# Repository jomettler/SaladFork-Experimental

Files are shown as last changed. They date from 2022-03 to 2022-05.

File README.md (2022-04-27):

# SaladFork-Experimental
Repository for Mods by me for the [SaladFork](https://github.com/PrintersForAnts/Salad_Fork) 3D Printer

This is a developement repository. Assume that all uploads are untested. There is absolutely no warranty on anything. 

Feel free to open issues or contact me directly in case you find any bugs.

ALSO: Some Mods contain Parts at least partly designed by [ANNEX-ENGINEERING](http://annex-engineering.com) I am not allowed to include these parts in my CAD, and their License applies to their designs. Due to this, these Parts are uploaded always in a sub-dir with their License File, which you should read carefully. I hate it, but I don´t have the time to do everything on my own and their designs are certainly better than a lot of stuff out there.

## Coming Soon
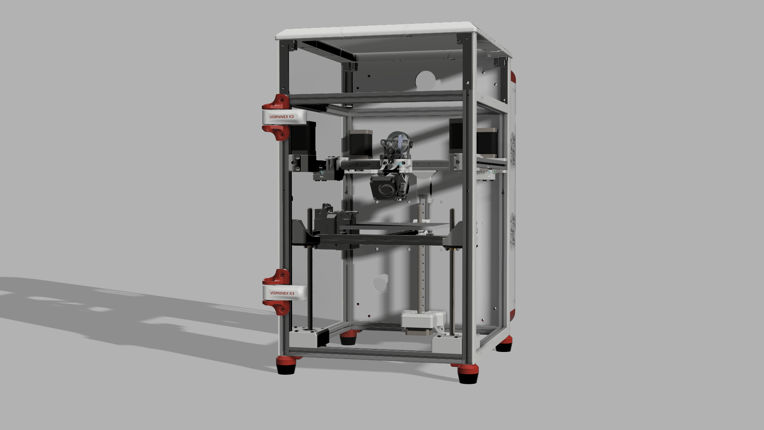
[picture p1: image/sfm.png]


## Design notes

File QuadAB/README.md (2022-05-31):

# Quad AB Drives for the SaladFork
Note that the XY Joints are basically mirrored compared to the orignal ones. They require the same build parts.The Idlers from the original tensioners are needed for the modificated drive mounts in the back.

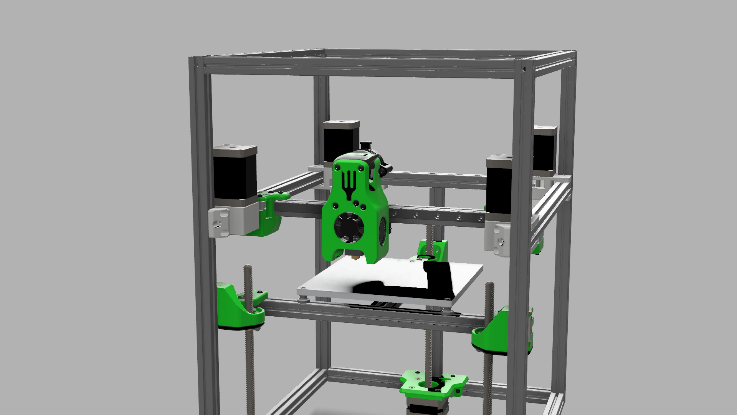
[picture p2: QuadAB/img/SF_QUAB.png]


## BOM
only additionaly needed parts are listed

2x NEMA14
2x Pulleys
screws & nuts

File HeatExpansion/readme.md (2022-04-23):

# heat expansion compensation stuff 

## General
This is most likely not relevant for small printers which print with a 0.4 Nozzle or bigger. The Machines below all have proven to work great for what they were (probably) designed for and they seem to meet critical criteria that is currently demanded both by manufactures and hobbyists. This area is of interest for higher precision machines and large builds that want to maintain the current stock precision. 

Heat sources: 
- hotend
- bed heater
- friction
- motors

A lot of work has been done on compensation for errors in printing resolution due to heat expansion (check out [tanaes](https://github.com/tanaes) nice work on the topic). Kinematic coupling for beds and titan or steel backers for gantry extrusions beeing the probably most popular solutions. But they usually come with some general flaws.

### [Annex K3](https://github.com/Annex-Engineering/Gasherbrum-K3):
While the Bed is directly mounted to extrusions, the kinematic coupling covers the expansion (and tilt) of the bed extrusions. The gantry rails are mounted in plastic or directly on the gantry extrusions. The design is inherently flawed concerning heat expansion of rails, frame (except bed extrusions) and bed.

### Voron [Trident](https://github.com/VoronDesign/Voron-Trident) / [Salad Fork](https://github.com/PrintersForAnts/Salad_Fork) / [2.4](https://github.com/VoronDesign/Voron-2) / [Micron](https://github.com/PrintersForAnts/Micron)
Titan and Steelbackers exist for the gantry extrusions. Kinematic mounting for the Bed. The bed extrusions (Trident style)/ gantry extrusions (2.4 Style) are mounted to the Z Rails using spherical bearings. Stock builds don´t have any solution for heat expansion errors. The designs are inherently flawed concerning expansion of the rails, frame, and bed. Also, the Z-Axis on these printers only work because of plastic beeing wobbly, due to massive overconstrain.

### Backers as a solution:
Backers follow a simple idea. If heat expansion creates a force in one direction that results in bending, we just need to create another force pulling in the opposite direction to compensate. But it neglects a lot of things: Thermal expansion is still happening and will induce stress into the system at various points. And they have a few obvious downsides since they are not 3D printable, take up space that could be utilized, expensive and add weight. It would be easier to not have this force in the first place, making compensating it unnecessary.

### Kinematic coupling for Beds:
Direct mounted Beds like on the [CroXY](https://github.com/CroXY3D/CroXY) are a simple and nice solution. But having extrusions to which the bed is mounted allows simple implementation of overtravel and cheaper beds. This benefit is kind of destroyed with the currently available kinematic couplings for beds, since they are usually CNC milled or cut from steel or titanium. This also adds unnecessary weight for moving Z machines and therefore make extrusion-mountable, 3D printed kinematic coupling for beds a necessity. 

### What about the Z-Rails?
Z Rails expand too. The solution with backers is just really inconvenient if panels are directly mounted from the opposite site. So usually no solution is applied.

## Mounting Linear Rails to Aluminium Extrusions:
The different heat expansion coefficient of the materials from the linear rails and extrusions results in a different elongation. Since they are static coupled, one of them can´t expand as much as necessary. This induces stress and, depending on the friction between the materials and material properties, leads to a bow. If we do not want this stress in our system, we need to allow the different elongation while preserving accuracy. The obvious solution for a 3D Printer is mounting the rail different.

Only one steel TNut is needed per rail. This one is mounted in the middle, the screw is fully tightend. This screw ideally locks all necessary degrees of freedom. Since it is not ideal, we support it a little. For all other holes in the rail, use a 3D printed TNut (preferably material with low friction coefficients). This nut should not apply ANY force in mounting direction of the rail, so just tighten them extremly gently with a little bit of loctide or something. Ideally, the printed nut fills the slot of the extrusion and is touching both, extrusion and rail. You can use a little bit of friction reducing material (grease, oil) between extrusion and nut. Also between Extrusion and Rail. Make sure the chosen material is compliant with the other components used. Now, heat expansion of the extrusion and the rail is decoupled. They can both elongate at their pace, since the printed TNuts can slide in the extrusion.

Note: The shape of your extrusions becomes a critical part for this kind of mount. Using quality extrusions is a necessity, else your rails might wobble in undesired directions.

Without the steel TNut tightend the rail should not wobble on the extrusion, but only move in the direction of the slot. You might have to tune your printer/slicer first.

## Bed
For the bed, we can use the exact same method. Instead of screwing it directly to the extrusions, we screw it on a plastic carriage that slides in the extrusion. This carriage needs low friction and high accuracy. On a V2.4 this still leaves the bed overconstrained. On a Trident style printer, this will result in a bed that is not expanding similar in all directions. Due to the T-like mounted bed extrusions, the fixed point of the bed moves to the front. This is probably irrelevant for small, 3-Axis machines, but might be an issue otherwise. Mounting the Bed extrusions Y-like solves this.

## Frame
With all rails decoupled from the frame, the frame can expand in all directions. Make sure that if your panels are directly bolted to the frame, the screws should not be tight and the mount holes in the panel should be a little oversized to allow elongation of the frame. Consider using only one steel TNut and TNuts printed in a material with low friction coefficients.

## This Repository
The STL Uploaded is for 15x15 extrusions according to the SF 150mm CAD. The f3d file can be used as an example how the Nut needs to be shaped to adapt for other extrusions. The STL should be printed with a 0.2 Nozzle, else issues might occur.

## Why no Data?
I enjoy using my brain and I don´t have enough time to test evertyhing by myself, so I though sharing might be a good thing in order to help others and myself. Data is highly appreciated. This repository does not intend to deliver a final answer or solution, but wants to introduce a possibly better approach for the problem at hand.

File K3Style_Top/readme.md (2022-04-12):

# K3 Style tophat for Saladfork

Inspired by the Tophat of the AnnexEngineering K3 (https://github.com/Annex-Engineering/Gasherbrum-K3)

Version for 10x3mm Magnets and 6x3mm Magnets

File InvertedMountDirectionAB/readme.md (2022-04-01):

# Adapted backside AB Drive Mounts for QuadAB

Mounts for AB Drives in the back. Adapted to mount the drive from the top. Endstop removed (sensorless homing)

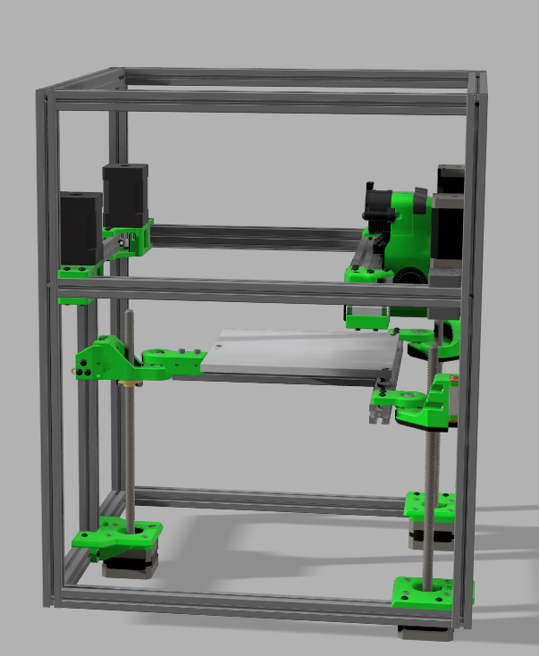
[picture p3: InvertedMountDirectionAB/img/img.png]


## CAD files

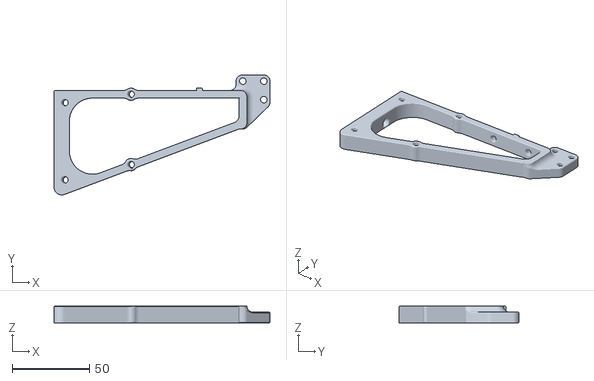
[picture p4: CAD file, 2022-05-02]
Misc/STL/SelfMaintenance/MountMain_x1.stl
140.0 x 77.8 x 11.0

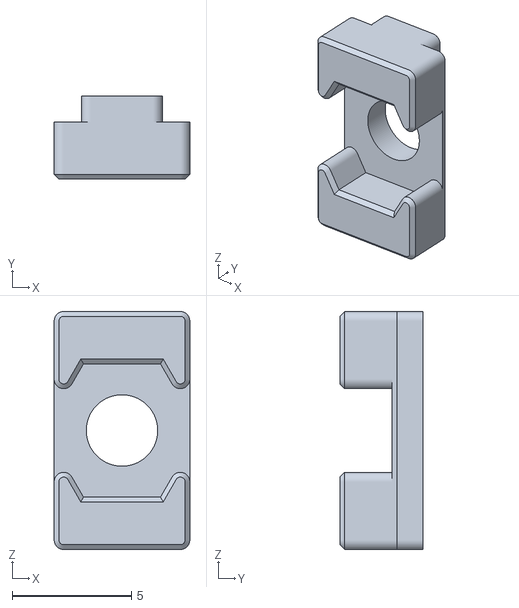
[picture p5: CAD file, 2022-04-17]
HeatExpansion/STL/TNut.stl
5.70 x 3.50 x 10.0

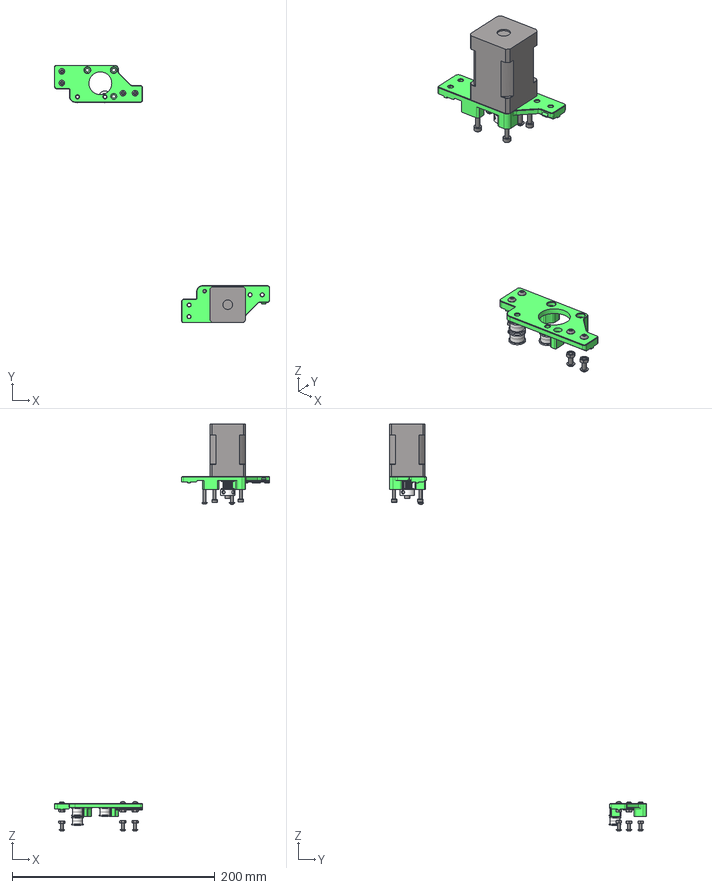
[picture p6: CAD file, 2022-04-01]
InvertedMountDirectionAB/CAD/B_Drive.step
212.4 x 253.9 x 401.4 mm
GT2 16T v2 (1) (1)(Mirror) (1) (1) (1)
M3 washer-1 (1) (1) x 12
M3x25 BHCS v1 (1) (1) x 2
M3x10 BHCS v1 (1) (1) x 8
M3_Hex_Nut v1 (2) (1) (2) x 4
M3_Hex_Nut v1 (1) (1) (1) (1) x 4
M3x25 SHCS v1 (1) (1) x 3
M3x8 BHCS v1 (1) (1) (1)
B_Drive_Frame_Upper (1)
B_Drive_Frame_Lower (1)

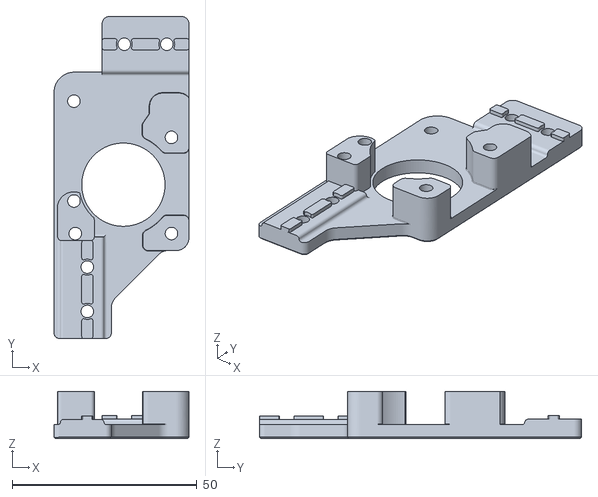
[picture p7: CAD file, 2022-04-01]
InvertedMountDirectionAB/STL/Lower_A.stl
36.5 x 87.1 x 12.8

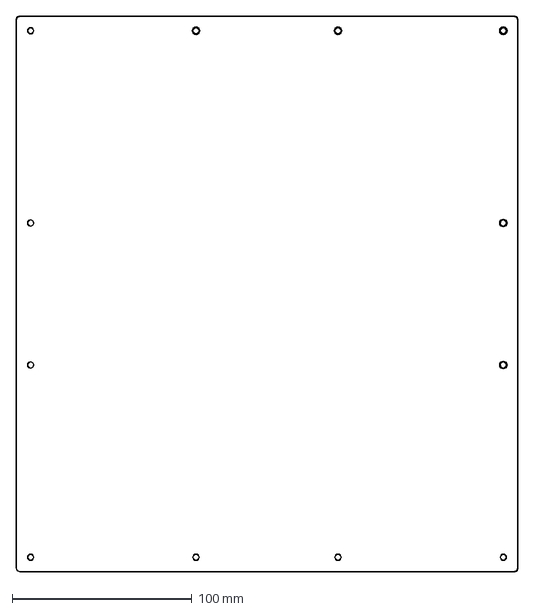
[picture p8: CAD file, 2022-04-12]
K3Style_Top/DXF/TopPanel.dxf
279.0 x 309.0 mm

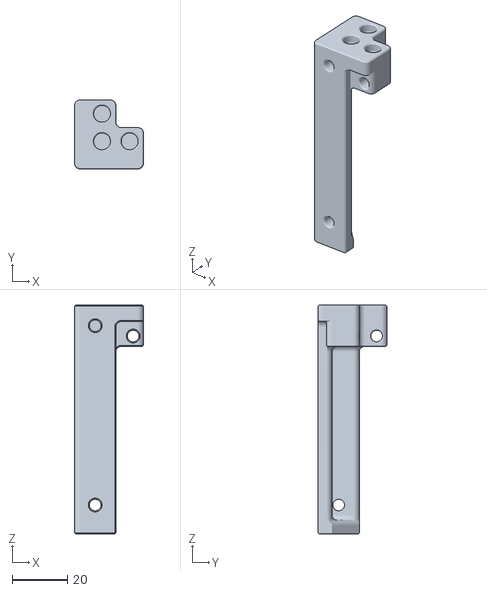
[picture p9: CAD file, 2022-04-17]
K3Style_Top/STL/Corner/6mm_x4.stl
25.0 x 25.0 x 83.0

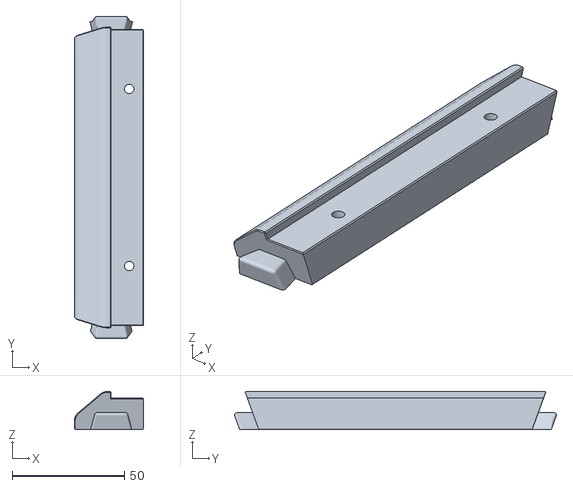
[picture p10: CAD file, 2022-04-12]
K3Style_Top/STL/Top/Long_x2.stl
31.0 x 143.6 x 17.0

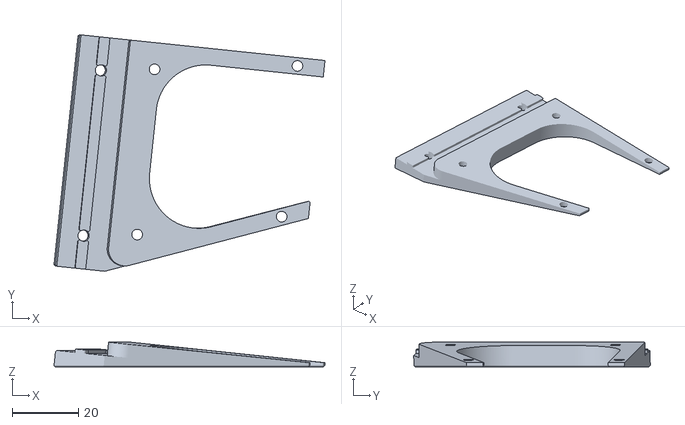
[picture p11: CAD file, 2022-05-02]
Misc/STL/SelfMaintenance/MountBrace_x1.stl
81.5 x 71.2 x 7.43

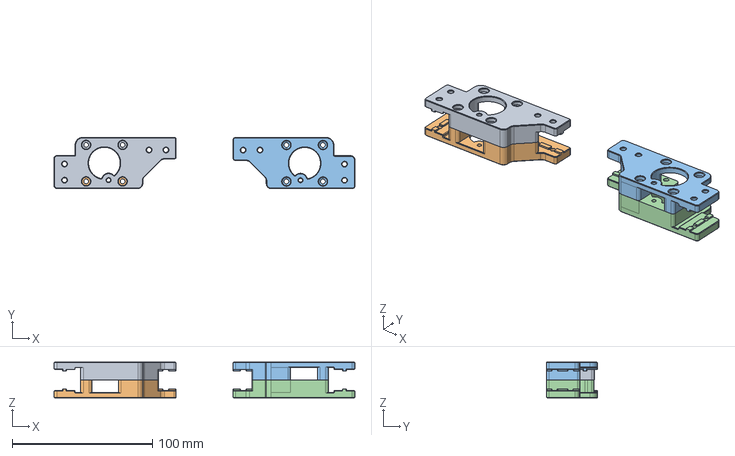
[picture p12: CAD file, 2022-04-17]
QuadAB/CAD/AB_DriveBack.step
214.5 x 36.6 x 25.5 mm
A Drive Frame v1
B Drive Frame (1) v1

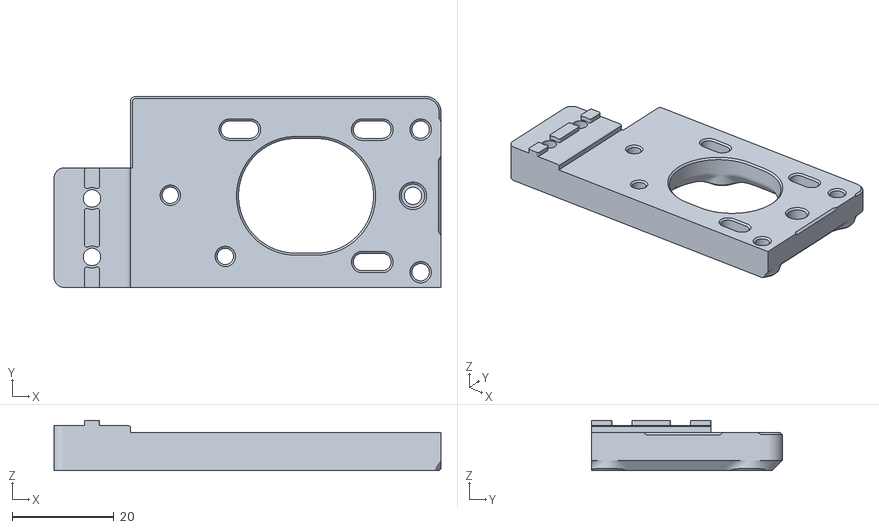
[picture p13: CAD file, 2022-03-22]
QuadAB/STL/A_Drive_Frame_Upper.stl
76.0 x 37.5 x 9.88

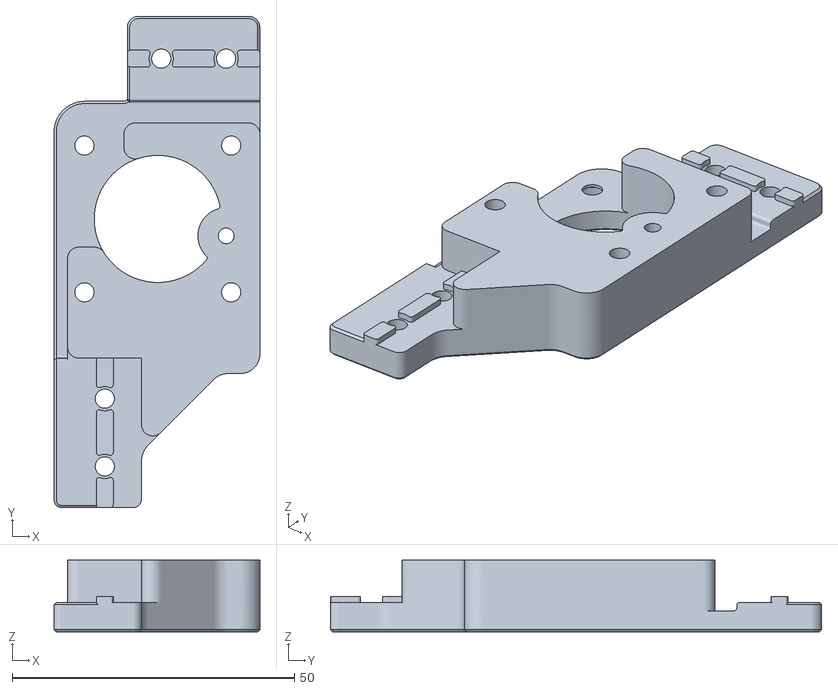
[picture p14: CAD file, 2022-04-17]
QuadAB/STL/Back/ALower.stl
36.5 x 87.1 x 12.8

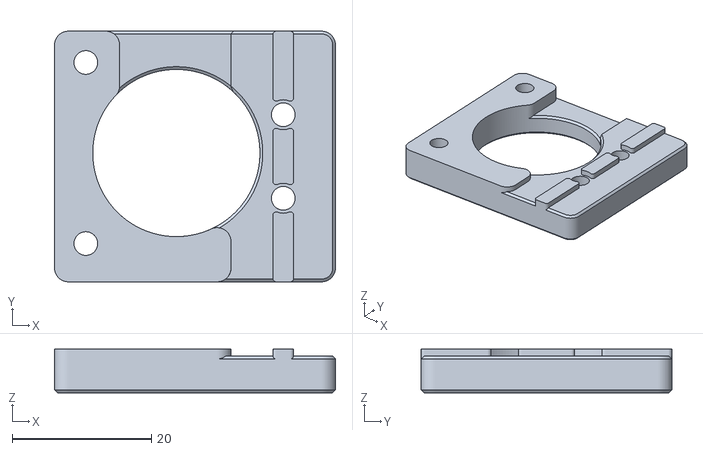
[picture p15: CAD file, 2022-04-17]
QuadAB/STL/NoIdler_Front/A_Bottom.stl
40.4 x 36.0 x 6.25

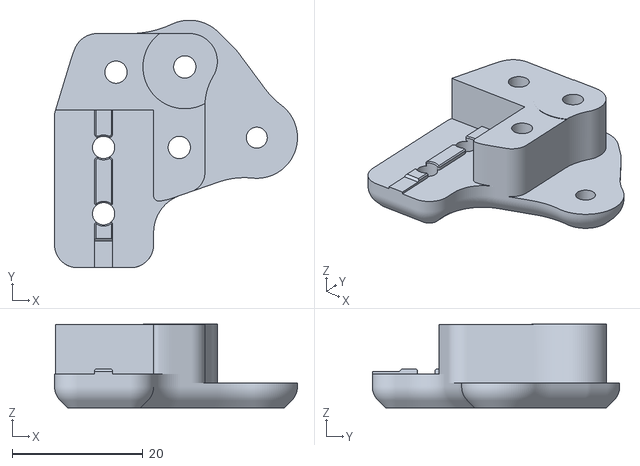
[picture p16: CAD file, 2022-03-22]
QuadAB/STL/XYJoints/XYJoint_left_top.stl
37.1 x 37.8 x 12.8

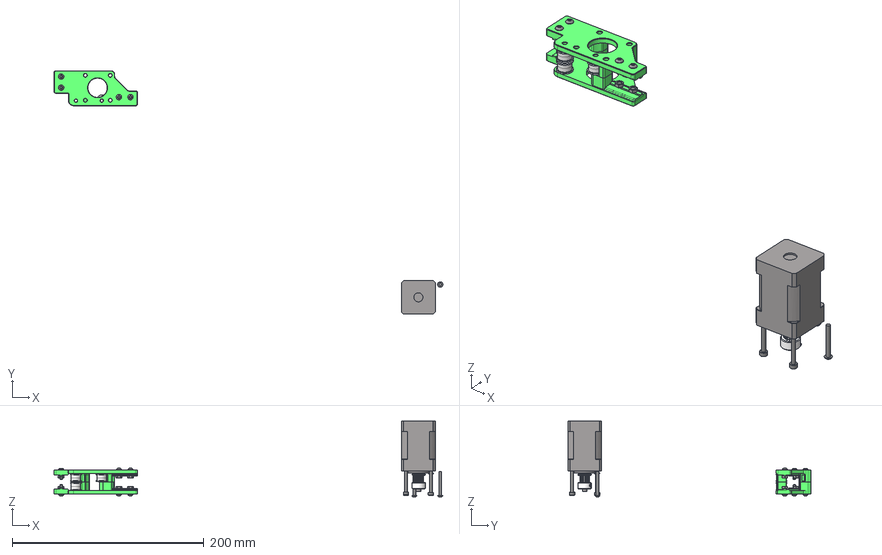
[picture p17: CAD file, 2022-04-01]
InvertedMountDirectionAB/CAD/A_Drive.step
405.4 x 253.8 x 78.9 mm
A_Drive_Frame_Lower (1)
A_Drive_Frame_Upper (1) (1)
GT2 16T v2 (1) (1)(Mirror) (3)
M3 washer-1 (1) x 12
M3_Hex_Nut v1 (2) (3) x 4
M3x10 BHCS v1 (1) x 4
M3_Hex_Nut v1 (1) (1) (3) x 4
M3x8 BHCS v1 (1) (2)
M3x25 SHCS v1 (1) x 3
M3x25 BHCS v1 (1) x 2
M3x10 BHCS v1 x 4

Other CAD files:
InvertedMountDirectionAB/STL/Lower_B.stl
K3Style_Top/STL/Corner/10mm_x4.stl
K3Style_Top/STL/Top/corner_10mm_x4.stl
QuadAB/CAD/NOIdler_FrontDrives.step
HeatExpansion/CAD/TNut_HeatExpansion v1.f3d
InvertedMountDirectionAB/CAD/A_Drive.f3d
InvertedMountDirectionAB/CAD/B_Drive.f3d
InvertedMountDirectionAB/STL/Upper_A.stl
InvertedMountDirectionAB/STL/Upper_B.stl
K3Style_Top/STL/Top/Corner_6mm_x4.stl
K3Style_Top/STL/Top/Short_x2.stl
QuadAB/CAD/XY-Joint_Left.step
QuadAB/CAD/XY-Joint_Right.step
QuadAB/STL/9mm_Spacer_x4.stl
QuadAB/STL/A_Drive_Frame_Holder.stl
QuadAB/STL/A_Drive_Frame_Lower.stl
QuadAB/STL/A_Drive_Tensioner.stl
QuadAB/STL/A_Tensioner_Knob.stl
QuadAB/STL/B_Drive_Frame_Holder.stl
QuadAB/STL/B_Drive_Frame_Lower.stl
QuadAB/STL/B_Drive_Frame_Upper.stl
QuadAB/STL/B_Drive_Tensioner.stl
QuadAB/STL/B_Tensioner_Knob.stl
QuadAB/STL/Back/AUpper.stl
QuadAB/STL/Back/BLower.stl
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

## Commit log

2022-03-22 QuadAB Mod
    [9mm_Spacer_x4.stl, A_Drive_Frame_Holder.stl, A_Drive_Frame_Lower.stl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]
2022-03-22 add CAD
2022-04-01 Add Inverted AB Back Mounts
    [A_Drive.f3d, A_Drive.step, B_Drive.f3d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]
2022-04-12 add K3 Style Tophat
    [10mm_x4.stl, 6mm_x4.stl, Corner_6mm_x4.stl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]
2022-04-17 corners support 10mm through hole magnets
    [10mm_x4.stl, 6mm_x4.stl]
2022-04-17 Add no Idler front drives
    [A_Bottom.stl, A_Tension.stl, A_Top.stl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]
2022-04-17 Add correct AB-back-drives
    [AB_DriveBack.step, ALower.stl, AUpper.stl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]
2022-04-17 clean up
    [9mm_Spacer_x4.stl, A_Drive_Frame_Holder.stl, A_Drive_Frame_Lower.stl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]
2022-04-17 Add heat stuff
    [TNut.stl, TNut_HeatExpansion v1.f3d]
2022-05-02 add self maintenance mount
    [MountBrace_x1.stl, MountMain_x1.stl]
